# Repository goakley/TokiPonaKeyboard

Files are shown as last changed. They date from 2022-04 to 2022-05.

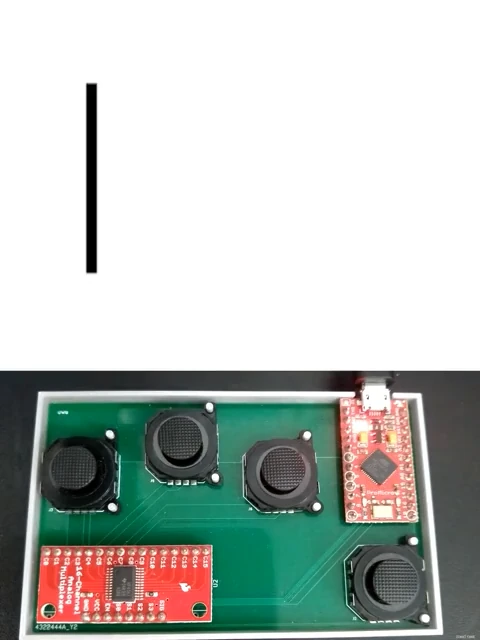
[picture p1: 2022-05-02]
docs/poster.webp

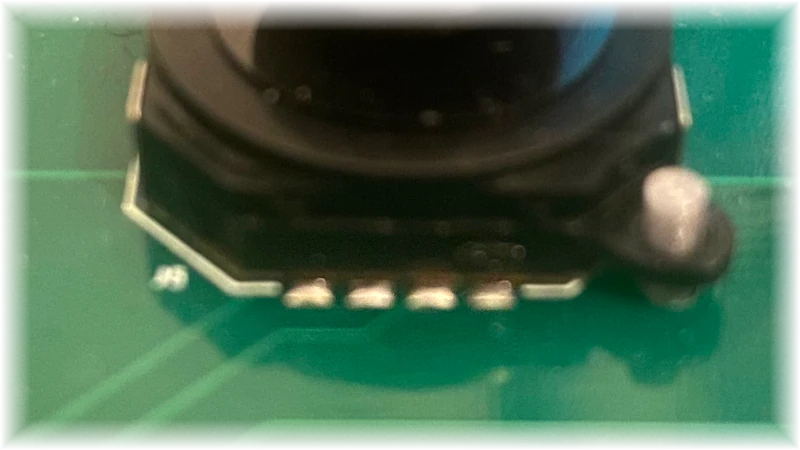
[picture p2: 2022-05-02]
docs/solder.webp

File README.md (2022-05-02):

# Toki Pona Keyboard

A 4-joystick input device, inspired by the sounds of [the Toki Pona language](https://tokipona.org/).

See [the website](https://goakley.github.io/TokiPonaKeyboard/) for more details on the keyboard, or the documentation in any of the subdirectories.

This project contains the following directories:

* `code` - The Arduino code that turns the hardware into a USB keyboard, plus other helpful tools
* `case` - The OpenSCAD files for the 3D model meant to house the electrical components of the keyboard
* `pcb`  - The KiCad project that defines the circuit board used in the keyboard
* `docs` - The project website and related documentation

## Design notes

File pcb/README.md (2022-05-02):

# Toki Pona Keyboard - PCB

This directory contains the entire KiCad project that describes the keyboard PCB.

The `gerbers` directory contains the exported gerber and drill files that can be sent directly to a PCB manufacturer.

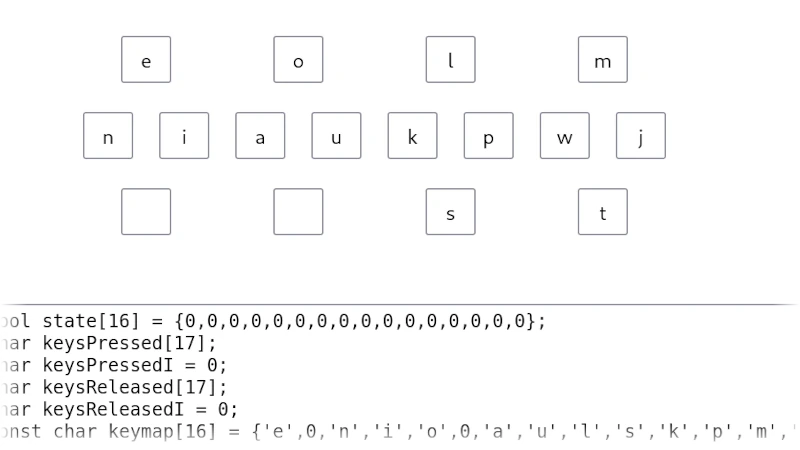
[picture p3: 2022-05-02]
docs/keymap.webp

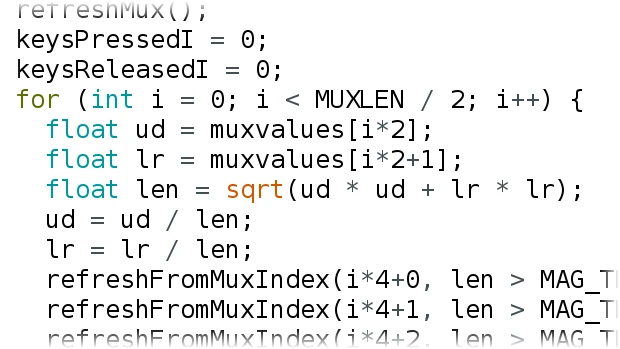
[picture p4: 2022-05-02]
docs/code.webp

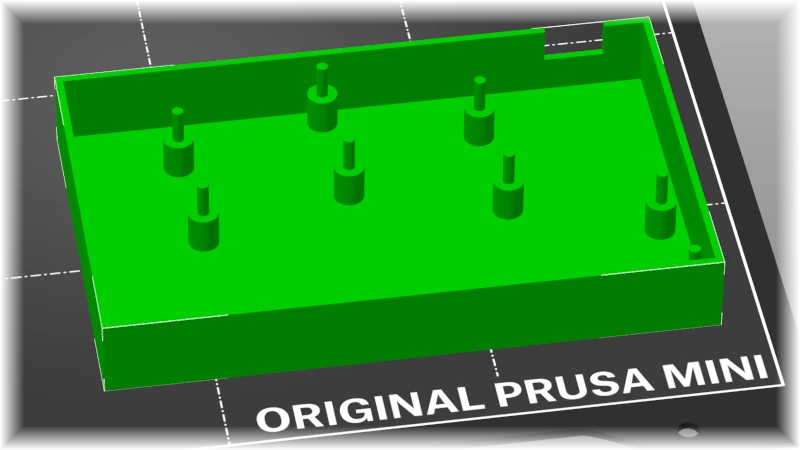
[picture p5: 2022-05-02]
docs/case.webp

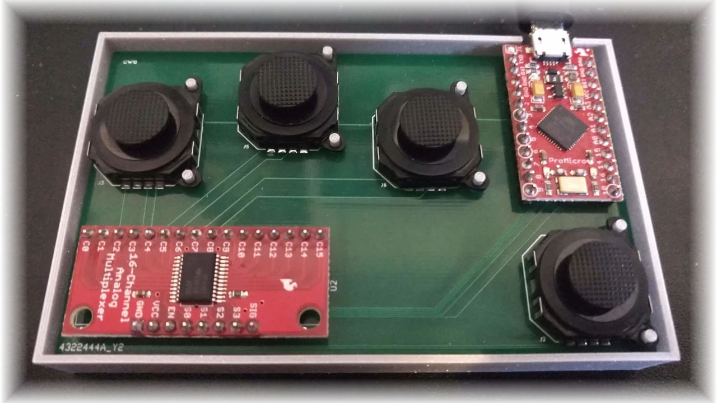
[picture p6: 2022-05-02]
docs/keyboard.webp

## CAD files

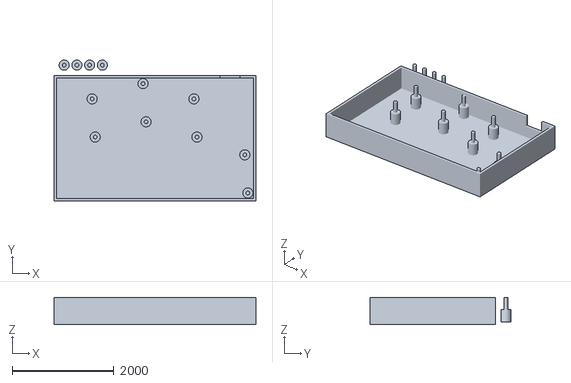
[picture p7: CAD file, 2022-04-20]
case/tokipona_pcb.stl
3970.0 x 2770.0 x 537.0

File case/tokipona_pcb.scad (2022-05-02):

// This program is free software: you can redistribute it and/or modify it under the terms of the GNU General Public License as published by the Free Software Foundation, either version 3 of the License, or (at your option) any later version.
// This program is distributed in the hope that it will be useful, but WITHOUT ANY WARRANTY; without even the implied warranty of MERCHANTABILITY or FITNESS FOR A PARTICULAR PURPOSE. See the GNU General Public License for more details.
// You should have received a copy of the GNU General Public License along with this program. If not, see <https://www.gnu.org/licenses/>.

// ALL UNITS IN MILS (1/1000in)
// Remember this when attempting to slice or upload your STL to a fabricator

// How high off the base of the container the PCB should sit
standheight = 250;
// The PCB/joysticks accept an M2 screw
// https://www.engineersedge.com/hardware/metric-external-thread-sizes1.htm
screwhole=75;
// The distance from the base of the joystick to the rounded top (NOT the stick itself)
joyheight = 175;
// The positions of the joysticks as placed in the PCB CAD
joypositions = [ [400,-800], [1400, -500], [2400, -800], [3400, -1900] ];
// How much space to leave between the walls of the container and the PCB
boxbuffer = 10;
// Where the USB port is positioned according to the PCB CAD
usbplace = 3400;
// How thick to make the walls of the container
wallsize=50;
// How many extra stands to print (for help with soldering the PCB)
extrastands = 4;
// The DXF drill file from the KiCad PCB project
// (use for referencing the PCB during development - DO NOT enable this during the final render)
dxf_file = undef; // "drill_map.dxf"
// Calculations for the size of the PCB, taken from the PCB CAD
pcbsize = [3850,2350];
// 62mil is 1.6mm which is "standard" PCB thickness
pcbthickness = 62;

pcbposition = [boxbuffer,boxbuffer];
boxsize=pcbsize+[boxbuffer*2,boxbuffer*2];
boxheight = standheight+pcbthickness+joyheight;

$fn=64;

// The pcb itself, for reference (do not include in the final render)
module pcb(dxf_file) {
    scale(1000) {
        translate([-1,1,0]) {
            intersection() {
                translate([0,-3.36,-0.53]) cube(10);
                linear_extrude(height = pcbthickness/1000, convexity = 10) import(dxf_file);
            }
        }
    }
}

// A single stand for the PCB
module stand(diameter) {
    cylinder(standheight, 100, 100);
    cylinder(boxheight, diameter/2, diameter/2);
}
// A pair of stands that supports one joystick
module standpair() {
    translate([290,396]) stand(screwhole);
    translate([350,-354]) stand(screwhole);
}

// The case itself
module case() {
    difference() {
        translate([-wallsize,-wallsize,-wallsize]){
            cube([boxsize[0]+wallsize*2,boxsize[1]+wallsize*2,boxheight+wallsize]);
        }
        union() {
            cube([boxsize[0],boxsize[1],boxheight+1]);
        }
        translate([boxbuffer+usbplace-200,boxsize[1]-1,standheight]) {
            cube([400,102,10000]);
        }
    }
    for (i = joypositions) {
        translate(pcbposition+[0,pcbsize[1]]+i) standpair();
    }
}
case();

// Loose parts to help with assembly
for (i = [1:1:extrastands]) translate([-100+250*i,boxsize[1]+wallsize+200,0]) stand(screwhole);

// The PCB (for reference - do not use in the final render)
if (dxf_file != undef) translate([pcbposition[0],pcbposition[1]+pcbsize[1],standheight]) pcb(dxf_file);

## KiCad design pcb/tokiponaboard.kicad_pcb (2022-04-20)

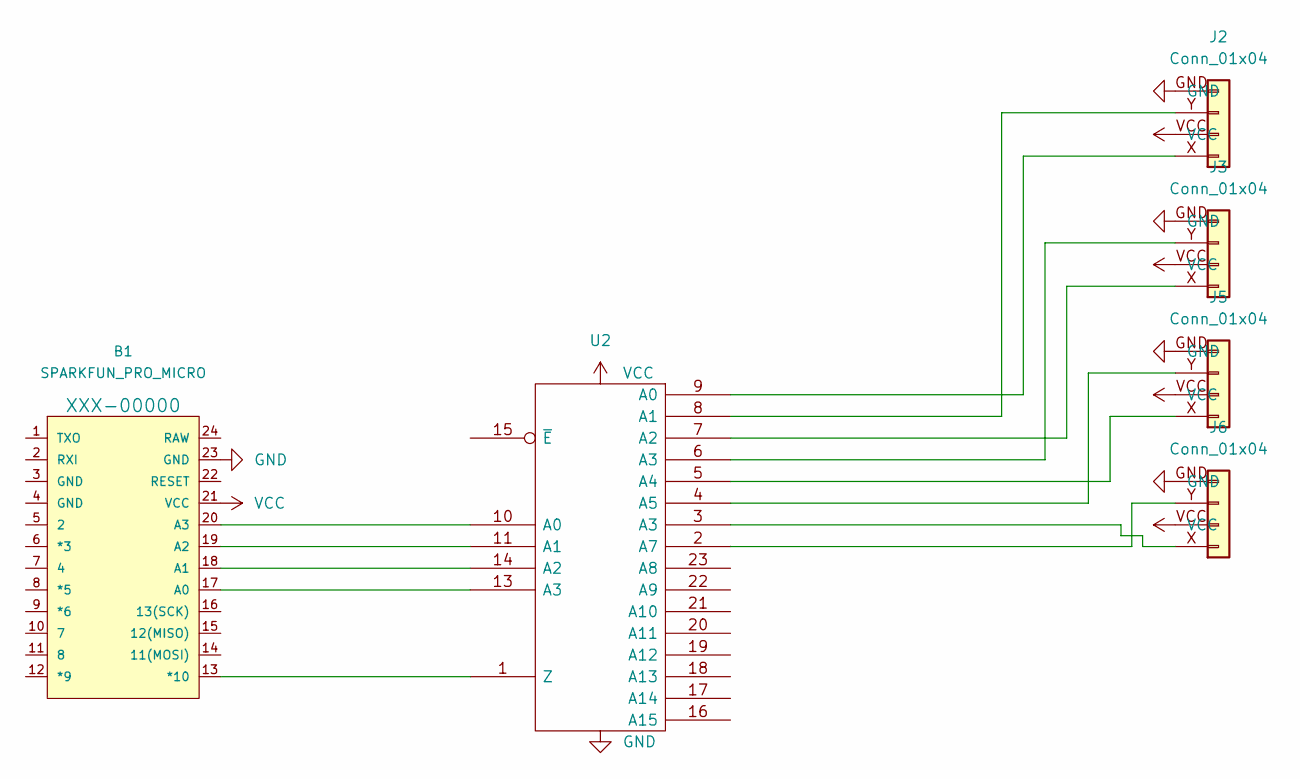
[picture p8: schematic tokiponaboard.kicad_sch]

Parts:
B1: SPARKFUN_PRO_MICRO
J2, J3, J5, J6: Conn_01x04; JOYSTICK-PSP1000
U2: (no value)

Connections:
GND: B1.23 (GND), J2.GND, J3.GND, J5.GND, J6.GND, U2.12 (Vss)
unnamed: B1.13 (*10), U2.1 (Z)
unnamed: B1.17 (A0), U2.13 (A3)
unnamed: B1.18 (A1), U2.14 (A2)
unnamed: B1.19 (A2), U2.11 (A1)
unnamed: B1.20 (A3), U2.10 (A0)
unnamed: J2.X, U2.9 (A0)
unnamed: J2.Y, U2.8 (A1)
unnamed: J3.X, U2.7 (A2)
unnamed: J3.Y, U2.6 (A3)
unnamed: J5.X, U2.5 (A4)
unnamed: J5.Y, U2.4 (A5)
unnamed: J6.X, U2.3 (A3)
unnamed: J6.Y, U2.2 (A7)
VCC: B1.21 (VCC), J2.VCC, J3.VCC, J5.VCC, J6.VCC, U2.24 (Vdd)

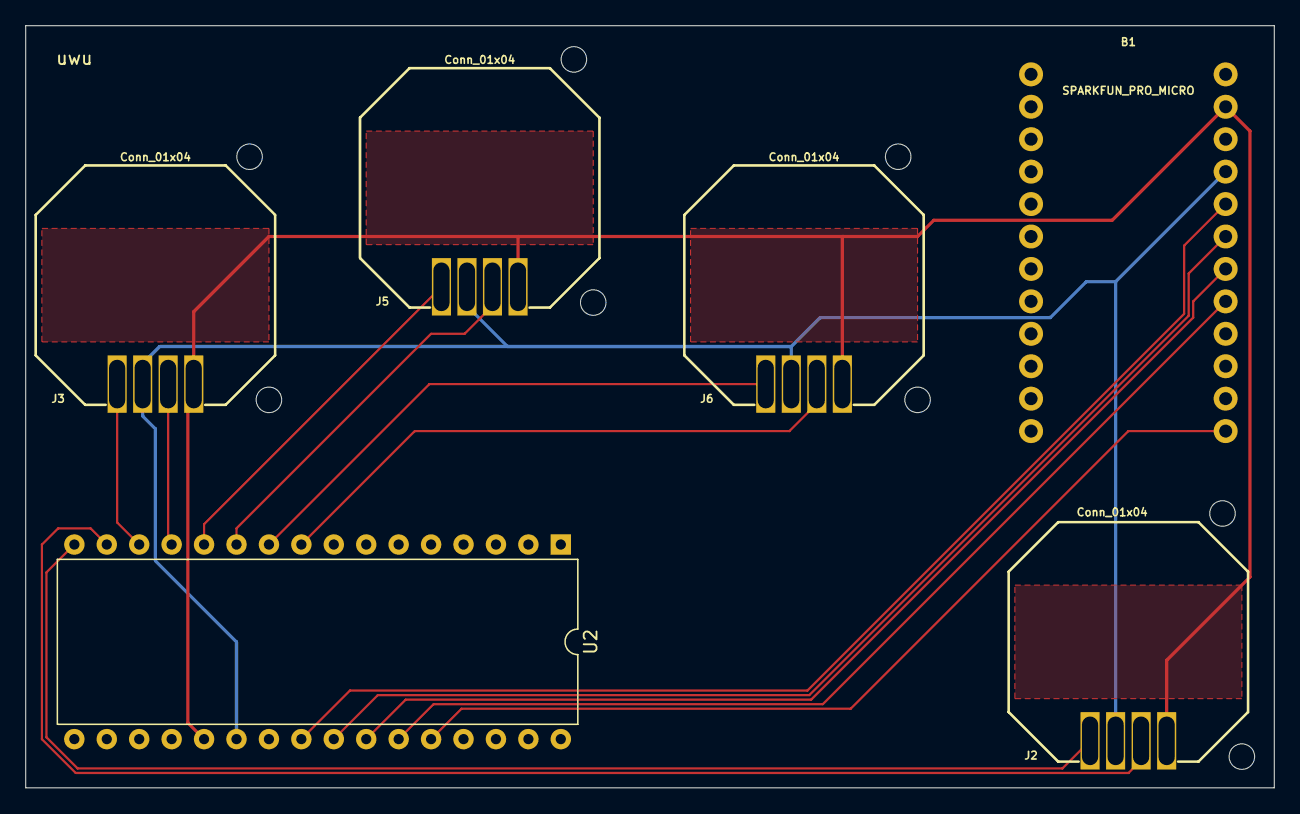
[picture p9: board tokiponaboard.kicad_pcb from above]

Board: 2 copper layers, 97.8 x 59.7 mm, 6 parts (0 on the bottom side), 15 nets.

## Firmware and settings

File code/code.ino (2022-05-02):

/*
This program is free software: you can redistribute it and/or modify it under the terms of the GNU General Public License as published by the Free Software Foundation, either version 3 of the License, or (at your option) any later version.
This program is distributed in the hope that it will be useful, but WITHOUT ANY WARRANTY; without even the implied warranty of MERCHANTABILITY or FITNESS FOR A PARTICULAR PURPOSE. See the GNU General Public License for more details.
You should have received a copy of the GNU General Public License along with this program. If not, see <https://www.gnu.org/licenses/>. 
*/
#include <Keyboard.h>

#define ANALOG_MAX 1023
#define ANALOG_THRESHOLD 0.33
#define MAG_THRESHOLD 0.5
#define ANG_THRESHOLD 0.7
#define PINLEN sizeof(pins)/sizeof(pins[0])
//define MUXLEN sizeof(muxvalues)/sizeof(muxvalues[0])
#define MUXLEN 8

// Easily switch between actual keyboard input and debugging over serial
#define KEYBRD 1
#if KEYBRD
#define WRITE Keyboard.write
#else
#define WRITE Serial.write
#endif

// MUX LOGIC
const byte pins[4] = {A3,A2,A1,A0};
const byte inpin = 10;
const byte muxtable[16][4] = {
  // {s0, s1, s2, s3}, // channel
  {0,  0,  0,  0}, // 0
  {1,  0,  0,  0}, // 1
  {0,  1,  0,  0}, // 2
  {1,  1,  0,  0}, // 3
  {0,  0,  1,  0}, // 4
  {1,  0,  1,  0}, // 5
  {0,  1,  1,  0}, // 6
  {1,  1,  1,  0}, // 7
  {0,  0,  0,  1}, // 8
  {1,  0,  0,  1}, // 9
  {0,  1,  0,  1}, // 10
  {1,  1,  0,  1}, // 11
  {0,  0,  1,  1}, // 12
  {1,  0,  1,  1}, // 13
  {0,  1,  1,  1}, // 14
  {1,  1,  1,  1}  // 15
};
int calibration[16] = {102,922,102,922,200,940,160,900,102,922,102,922,200,940,160,900};
int records[16] = {9999,-1,9999,-1,9999,-1,9999,-1,9999,-1,9999,-1,9999,-1,9999,-1};
//int calibration[16] = {410,614,410,614,410,614,410,614,410,614,410,614,410,614,410,614};
bool recalibrate = false;
float muxvalues[16];
// fill muxvalues with values in the range [-1,1] (probably) for each channel
void refreshMux() {
  for (int i = 0; i < MUXLEN; i++) {
    digitalWrite(pins[0], muxtable[i][0]);
    digitalWrite(pins[1], muxtable[i][1]);
    digitalWrite(pins[2], muxtable[i][2]);
    digitalWrite(pins[3], muxtable[i][3]);
    delayMicroseconds(4);
    int value = analogRead(inpin);
    records[i*2] = min(records[i*2], value);
    records[i*2+1] = max(records[i*2+1], value);
    int minv = calibration[i*2];
    int maxv = calibration[i*2+1];
    //muxvalues[i] = (2 * ((float)value) / ((float)ANALOG_MAX)) - 1;
    muxvalues[i] = (2 * ((float)(value - minv)) / ((float)(maxv - minv))) - 1;
  }
}

bool state[16] = {0,0,0,0,0,0,0,0,0,0,0,0,0,0,0,0};
char keysPressed[17];
char keysPressedI = 0;
char keysReleased[17];
char keysReleasedI = 0;

// vowel-cluster mapping
//const char keymap[16] = {'j','w','m','t','i','n','e',0,'u','a','o',0,'p','k','l','s'};
// vowel-pair mapping (o floating)
//const char keymap[16] = {'w','m','j',0,'n','l','a','i','t','k','e','u','p','s','o',0};
// vowel-pair mapping (u floating)
const char keymap[16] = {'w','m','j',8,'n','l','a','i','t','k','e','o','p','s','u','.'};

void refreshFromMuxIndex(int index, bool active) {
  if (keymap[index]) {
    if (active) {
      if (!state[index]) {
        keysPressed[keysPressedI++] = keymap[index];
      }
      state[index] = 1;
    } else {
      if (state[index]) {
        keysReleased[keysReleasedI++] = keymap[index];
      }
      state[index] = 0;
    }
  }
}

void refreshFromMux() {
  refreshMux();
  keysPressedI = 0;
  keysReleasedI = 0;
  for (int i = 0; i < MUXLEN / 2; i++) {
    float ud = muxvalues[i*2];
    float lr = muxvalues[i*2+1];
    float len = sqrt(ud * ud + lr * lr);
    ud = ud / len;
    lr = lr / len;
    refreshFromMuxIndex(i*4+0, len > MAG_THRESHOLD && ud > ANG_THRESHOLD);
    refreshFromMuxIndex(i*4+1, len > MAG_THRESHOLD && ud < -ANG_THRESHOLD);
    refreshFromMuxIndex(i*4+2, len > MAG_THRESHOLD && lr > ANG_THRESHOLD);
    refreshFromMuxIndex(i*4+3, len > MAG_THRESHOLD && lr < -ANG_THRESHOLD);
  }
  //Serial.println("");
  keysPressed[keysPressedI] = 0;
  keysReleased[keysReleasedI] = 0;
}

void setup() {
  for (int i = 0; i < PINLEN; i++) {
    pinMode(pins[i], OUTPUT);
  }
  pinMode(inpin, INPUT);
  Serial.begin(9600);
  delay(128);
  while (!Serial) ;
  #if KEYBRD
  Keyboard.begin();
  #endif
}

unsigned long lastRecord = 0;
unsigned long loops = 0;

void debug(unsigned long duration) {
  Serial.println();
  for (int i =0; i < MUXLEN; i++) {
    Serial.print(records[i*2]);
    Serial.print(" ");
    Serial.print(records[i*2+1]);
    Serial.print(" ");
  }
  Serial.print("| ");
  Serial.print(((float)duration) / ((float)loops));
  Serial.println();
}

void loop() {
  refreshFromMux();

  unsigned long now = millis();
  if (now - lastRecord > 1000) {
    int inp = Serial.read();
    if (inp == 'd') {
      debug(now - lastRecord);
    }
    loops = 0;
    lastRecord = now;
  }
  
  int i = 0;
  while (i < keysPressedI) {
    WRITE(keysPressed[i]);
    i++;
  }
  if (i > 0) {
    Serial.flush();
  }
  loops++;
}

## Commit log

2022-04-20 Add case
    [tokipona_pcb.scad, tokipona_pcb.stl]
2022-04-20 Clean up the openscad file
    [tokipona_pcb.scad, tokipona_pcb.stl]
2022-04-20 add license
    [tokipona_pcb.scad]
2022-04-20 Add code (arduino and keymap)
2022-05-02 Add README with additional documentation
    [tokipona_pcb.scad]
2022-05-02 Add missing control character from keymap
    [code.ino]
